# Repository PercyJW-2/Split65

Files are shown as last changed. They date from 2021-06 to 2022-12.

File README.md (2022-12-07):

# Split65
Split 65 Percent Keyboard

## Features
- ProMicro and Proton C support
- QMK Port
- Hot-Swap
- I2C support (not implemented in QMK-Port)

## Instructions
- when using an Proton C
  - R2 needs to be populated with an Resistor with an value of 3k3 up to 6k8
  - R3 needs to be populated with an resistor with an value of 100
- when using an ProMicro
  - R3 needs to be shorted
- when using I2C
  - R1 and R2 need to be populated with an apropriate Resistor
  - both jumpers need to be shorted

## Images


### Left


### Right


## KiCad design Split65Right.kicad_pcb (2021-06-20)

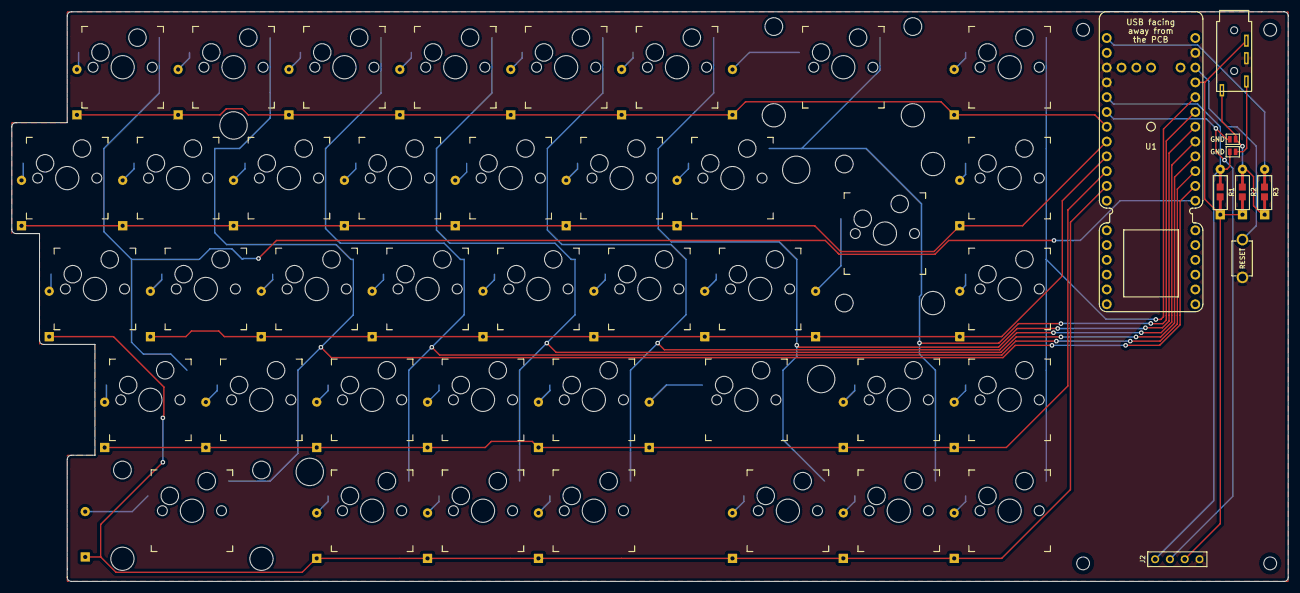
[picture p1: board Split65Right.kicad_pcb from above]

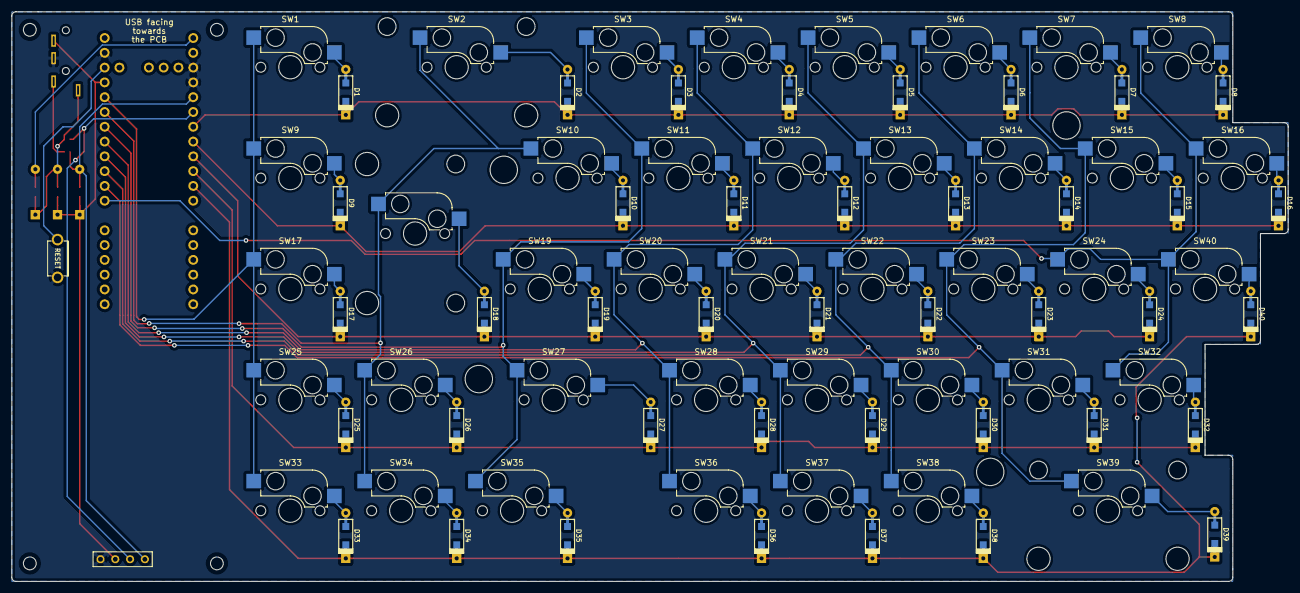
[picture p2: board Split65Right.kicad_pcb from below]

Board: 2 copper layers, 219.2 x 97.8 mm, 97 parts (40 on the bottom side), 60 nets.

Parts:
D1, D2, D3, D4, D5, D6, D7, D8, D9, D10, D11, D12, D13, D14, D15, D16, D17, D18, D19, D20, D21, D22, D23, D24, D25, D26, D27, D28, D29, D30, D31, D32, D33, D34, D35, D36, D37, D38, D39, D40: D; D_SOD123_axial
HOLE_3M, HOLE_3M#2, HOLE_3M#3, HOLE_3M#4: VAL**; HOLE_M2_TH
HOLE_M2, HOLE_M2#2, HOLE_M2#3, HOLE_M2#4: VAL**; HOLE_M2
J1: Jack4; TRRS_JACK_MJ4PP9
J2: OLED; OLED_4Pin
JP2, JP3: GND; Jumper
R1, R2: 5k; R_1608_axial
R3: 120; R_1608_axial
SW1, SW3, SW4, SW5, SW6, SW7, SW8, SW9, SW10, SW11, SW12, SW13, SW14, SW15, SW16, SW17, SW19, SW20, SW21, SW22, SW23, SW24, SW25, SW26, SW28, SW29, SW30, SW31, SW32, SW33, SW34, SW35, SW36, SW37, SW38, SW40: SW_PUSH; KailhSocket-1U
SW2: SW_PUSH; KailhSocket-2U
SW18: SW_PUSH; KailhSocket-ISO
SW27: SW_PUSH; KailhSocket-1.75U
SW39: SW_PUSH; KailhSocket-2.25U
SW_41: SW_Push; TACT_SWITCH_TVBP06
U1: Proton_C; proton_c

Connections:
+3V3: J2.3, R1.1, R2.1, U1.3.3V
COL0: SW1.1, SW9.1, SW17.1, SW25.1, SW33.1, U1.A2
COL1: SW2.1, SW10.1, SW18.1, SW26.1, SW34.1, U1.A1
COL2: SW3.1, SW11.1, SW19.1, SW27.1, SW35.1, U1.A0
COL3: SW4.1, SW12.1, SW20.1, SW28.1, SW36.1, U1.B8
COL4: SW5.1, SW13.1, SW21.1, SW29.1, SW37.1, U1.B13
COL5: SW6.1, SW14.1, SW22.1, SW30.1, SW38.1, U1.B14
COL6: SW7.1, SW15.1, SW23.1, SW31.1, SW39.1, U1.B15
COL7: SW8.1, SW16.1, SW24.1, SW32.1, SW40.1, U1.B9
DATA: R3.2, U1.A9
GND: J1.C, J2.4, SW_41.1, U1.GND
unnamed: D1.2, SW1.2
unnamed: D2.2, SW2.2
unnamed: D3.2, SW3.2
unnamed: D4.2, SW4.2
unnamed: D5.2, SW5.2
unnamed: D6.2, SW6.2
unnamed: D7.2, SW7.2
unnamed: D8.2, SW8.2
unnamed: D9.2, SW9.2
unnamed: D10.2, SW10.2
unnamed: D11.2, SW11.2
unnamed: D12.2, SW12.2
unnamed: D13.2, SW13.2
unnamed: D14.2, SW14.2
unnamed: D15.2, SW15.2
unnamed: D16.2, SW16.2
unnamed: D17.2, SW17.2
unnamed: D18.2, SW18.2
unnamed: D19.2, SW19.2
unnamed: D20.2, SW20.2
unnamed: D21.2, SW21.2
unnamed: D22.2, SW22.2
unnamed: D23.2, SW23.2
unnamed: D24.2, SW24.2
unnamed: D25.2, SW25.2
unnamed: D26.2, SW26.2
unnamed: D27.2, SW27.2
unnamed: D28.2, SW28.2
unnamed: D29.2, SW29.2
unnamed: D30.2, SW30.2
unnamed: D31.2, SW31.2
unnamed: D32.2, SW32.2
unnamed: D33.2, SW33.2
unnamed: D34.2, SW34.2
unnamed: D35.2, SW35.2
unnamed: D36.2, SW36.2
unnamed: D37.2, SW37.2
unnamed: D38.2, SW38.2
unnamed: D39.2, SW39.2
unnamed: D40.2, SW40.2
unnamed: JP3.1, R2.2, R3.1
RESET: SW_41.2, U1.DFU
ROW0: D1.1, D2.1, D3.1, D4.1, D5.1, D6.1, D7.1, D8.1, U1.B5
ROW1: D9.1, D10.1, D11.1, D12.1, D13.1, D14.1, D15.1, D16.1, U1.B4
ROW2: D17.1, D18.1, D19.1, D20.1, D21.1, D22.1, D23.1, D24.1, U1.B3
ROW3: D25.1, D26.1, D27.1, D28.1, D29.1, D30.1, D31.1, D32.1, U1.B2
ROW4: D33.1, D34.1, D35.1, D36.1, D37.1, D38.1, D39.1, D40.1, U1.B1
SCL: J2.2, JP3.2, U1.B6
SDA: J2.1, JP2.2, R1.2, U1.B7

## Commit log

2020-10-04 modified: Split65Left-cache.lib modified: Split65Left.kicad_pcb modified: Split65Left.kicad_pcb-bak modified: Split65Left.net modified: Split65Left.sch modified: Split65Left.sch-bak modified: Split65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
    [Split65Left.kicad_pcb, Split65Left.sch, Split65Right.kicad_pcb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]
2020-10-10 Added Plates for left side
    [Split65Left.kicad_pcb]
2020-11-05 Updated some small things - removed 3u buttons
    [BackPlateLeft.dxf, BackPlateRight.dxf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]
2020-11-12 removed wrongly scaled dxf files deleted: BackPlateLeft.dxf deleted: BackPlateRight.dxf modified: ../fp-info-cache
    [BackPlateLeft.dxf, BackPlateRight.dxf]
2021-06-20 Fixed Critical Error: Ground between the two halves was not connected
    [Split65Left.kicad_pcb, Split65Right.kicad_pcb]
2021-06-20 updated gerber files
    [Split65Left-B_Cu.gbr, Split65Left-B_Mask.gbr, Split65Left-B_Paste.gbr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]
